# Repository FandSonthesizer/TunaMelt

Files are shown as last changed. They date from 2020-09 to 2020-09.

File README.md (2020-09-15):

# TunaMelt
Our Tuna Melt clone. 

This is out attempt to build a Tuna Melt clone. We changed it to have a true bypass, also we are using standart parts which are not hard to get by.
The Vactrol consists of an LDR03 light sensitive resistor and a white 3mm LED, bound together head on head with some black electrical tape.

So we re-named it the FnS Melt. :-)

This effect just sounds great, a very nice Tremolo indeed!

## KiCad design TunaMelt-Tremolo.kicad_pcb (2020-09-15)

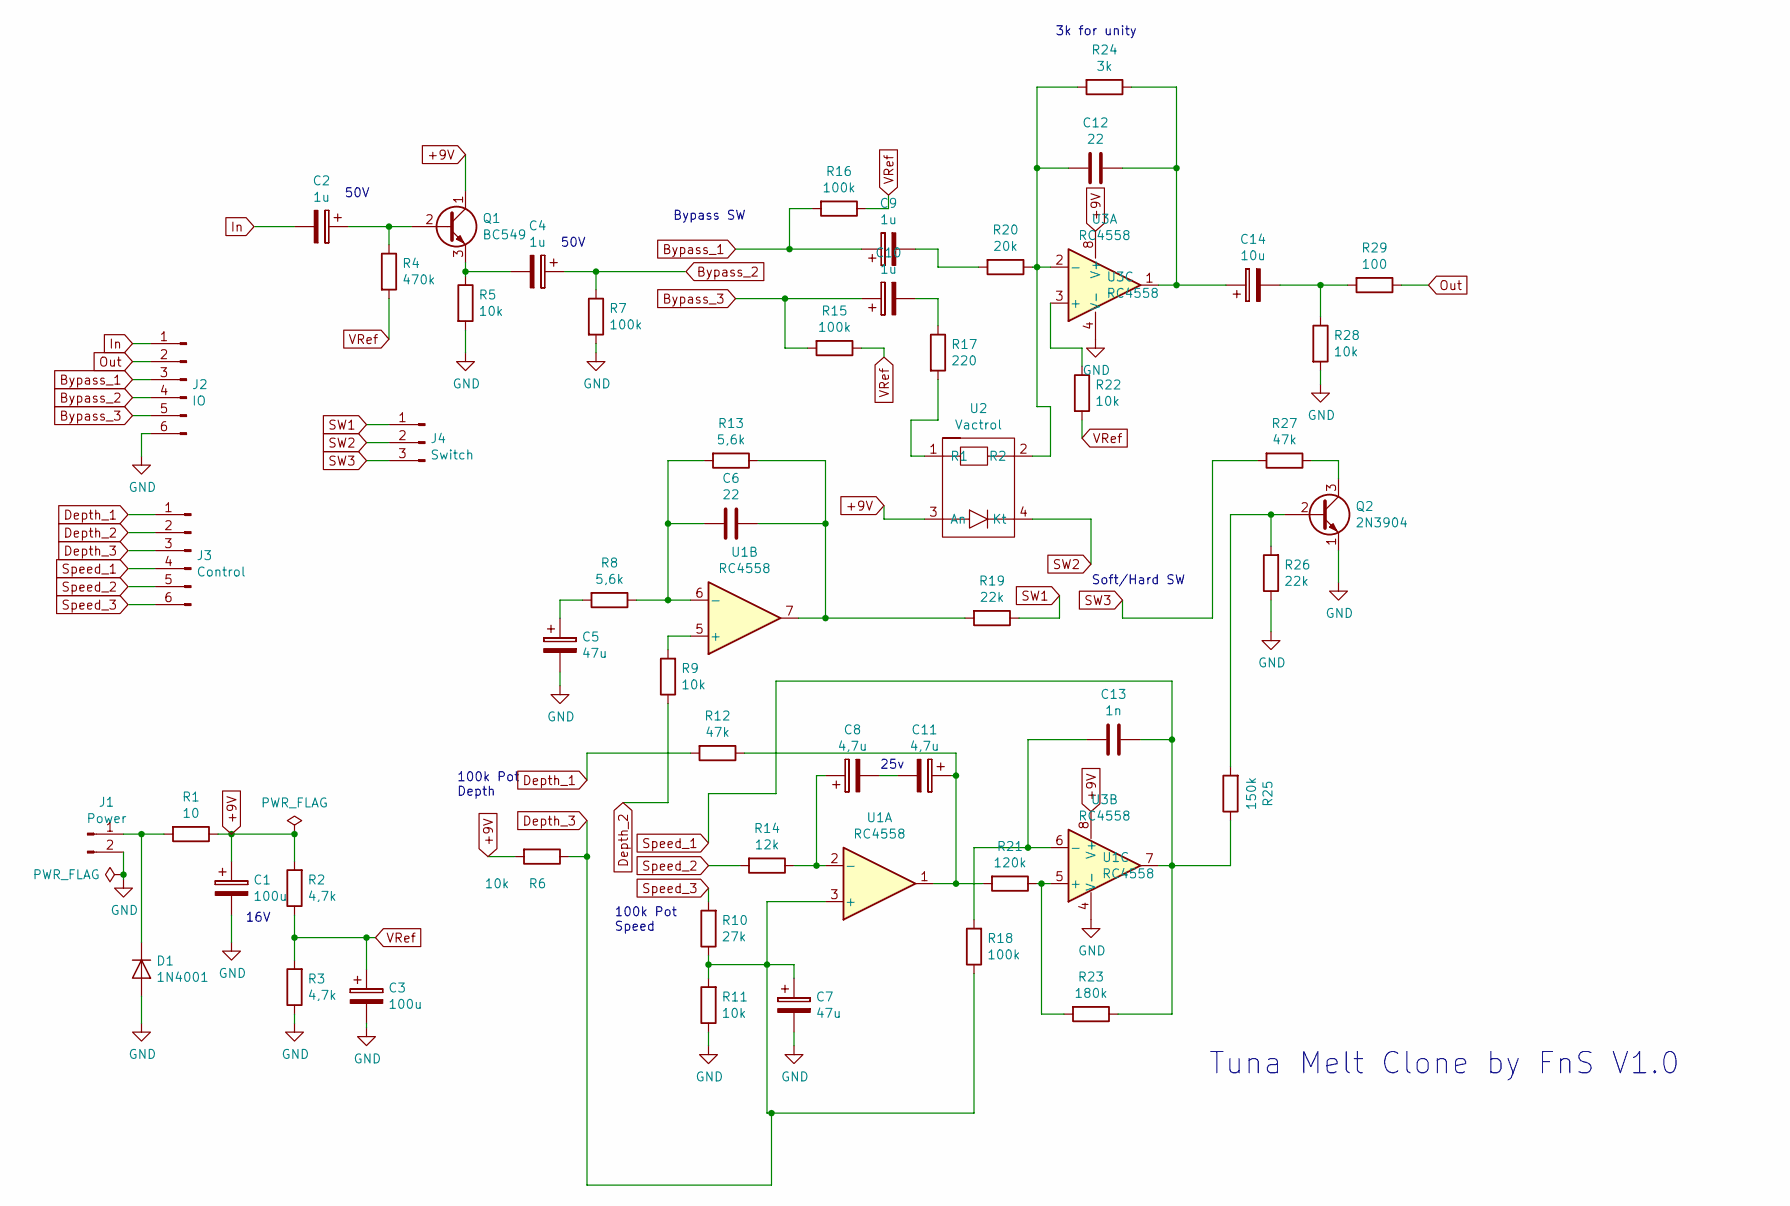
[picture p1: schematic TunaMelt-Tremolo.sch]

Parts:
C1, C3: 100u; Elko_D6.3mm_P2.50mm
C2, C4, C9, C10: 1u; Elko_D6.3mm_P2.50mm
C5, C7: 47u; Elko_D6.3mm_P2.50mm
C6, C12: 22; Kondensator_Keramik
C8, C11: 4,7u; Elko_D6.3mm_P2.50mm
C13: 1n; Kondensator_Keramik
C14: 10u; Elko_D6.3mm_P2.50mm
D1: 1N4001; Diode_Horizontal
J1: Power; Stift_x02
J2: IO; PinHeader_1x06_P2.54mm_Vertical_NIK
J3: Control; PinHeader_1x06_P2.54mm_Vertical_NIK
J4: Switch; Stift_0x3
Q1: BC549; TO-92_Wide_NIK
Q2: 2N3904; TO-92_Wide_NIK
R1: 10; Widerstand_liegend
R2, R3: 4,7k; Widerstand_liegend
R4: 470k; Widerstand_liegend
R5, R6, R9, R11, R22, R28: 10k; Widerstand_liegend
R7, R15, R16, R18: 100k; Widerstand_liegend
R8, R13: 5,6k; Widerstand_liegend
R10: 27k; Widerstand_liegend
R12, R27: 47k; Widerstand_liegend
R14: 12k; Widerstand_liegend
R17: 220; Widerstand_liegend
R19, R26: 22k; Widerstand_liegend
R20: 20k; Widerstand_liegend
R21: 120k; Widerstand_liegend
R23: 180k; Widerstand_liegend
R24: 3k; Widerstand_liegend
R25: 150k; Widerstand_liegend
R29: 100; Widerstand_liegend
U1, U3: RC4558; DIP-8_W7.62mm_Socket_LongPads
U2: Vactrol

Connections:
+9V: C1.1, Q1.1 (C), R1.1, R2.2, R6.2, U1.8 (V+), U2.3 (An), U3.8 (V+)
Bypass_1: C9.1, J2.3, R16.2
Bypass_2: C4.1, J2.4, R7.1
Bypass_3: C10.1, J2.5, R15.2
Depth_1: J3.1, R12.2
Depth_2: J3.2, R9.1
Depth_3: C7.1, J3.3, R6.1, R10.1, R11.2, R18.1, U1.3 (+)
GND: C1.2, C3.2, C5.2, C7.2, D1.2 (A), J1.2, J2.6, Q2.1 (E), R3.1, R5.2, R7.2, R11.1, R26.1, R28.2, U1.4 (V-), U3.4 (V-)
In: C2.2, J2.1
unnamed: C2.1, Q1.2 (B), R4.1
unnamed: C4.2, Q1.3 (E), R5.1
unnamed: C5.1, R8.2
unnamed: C6.1, R13.1, R19.2, U1.7
unnamed: C6.2, R8.1, R13.2, U1.6 (-)
unnamed: C8.1, R14.1, U1.2 (-)
unnamed: C9.2, R20.2
unnamed: C10.2, R17.1
unnamed: C11.1, R12.1, R21.2, U1.1
unnamed: C8.2, C11.2
unnamed: C12.1, C14.1, R24.1, U3.1
unnamed: C12.2, R20.1, R24.2, U2.2 (R2), U3.2 (-)
unnamed: C13.2, R18.2, U3.6 (-)
unnamed: C14.2, R28.1, R29.2
unnamed: D1.1 (K), J1.1, R1.2
unnamed: Q2.2 (B), R25.2, R26.2
unnamed: Q2.3 (C), R27.1
unnamed: R9.2, U1.5 (+)
unnamed: R17.2, U2.1 (R1)
unnamed: R21.1, R23.2, U3.5 (+)
unnamed: R22.1, U3.3 (+)
Out: J2.2, R29.1
SW1: J4.1, R19.1
SW2: J4.2, U2.4 (Kt)
SW3: J4.3, R27.2
Speed_1: C13.1, J3.4, R23.1, R25.1, U3.7
Speed_2: J3.5, R14.2
Speed_3: J3.6, R10.2
VRef: C3.1, R2.1, R3.2, R4.2, R15.1, R16.1, R22.2

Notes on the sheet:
50V
Bypass SW
Soft/Hard SW
100k Pot Depth
100k Pot Speed
16V
25v
Tuna Melt Clone by FnS V1.0
3k for unity

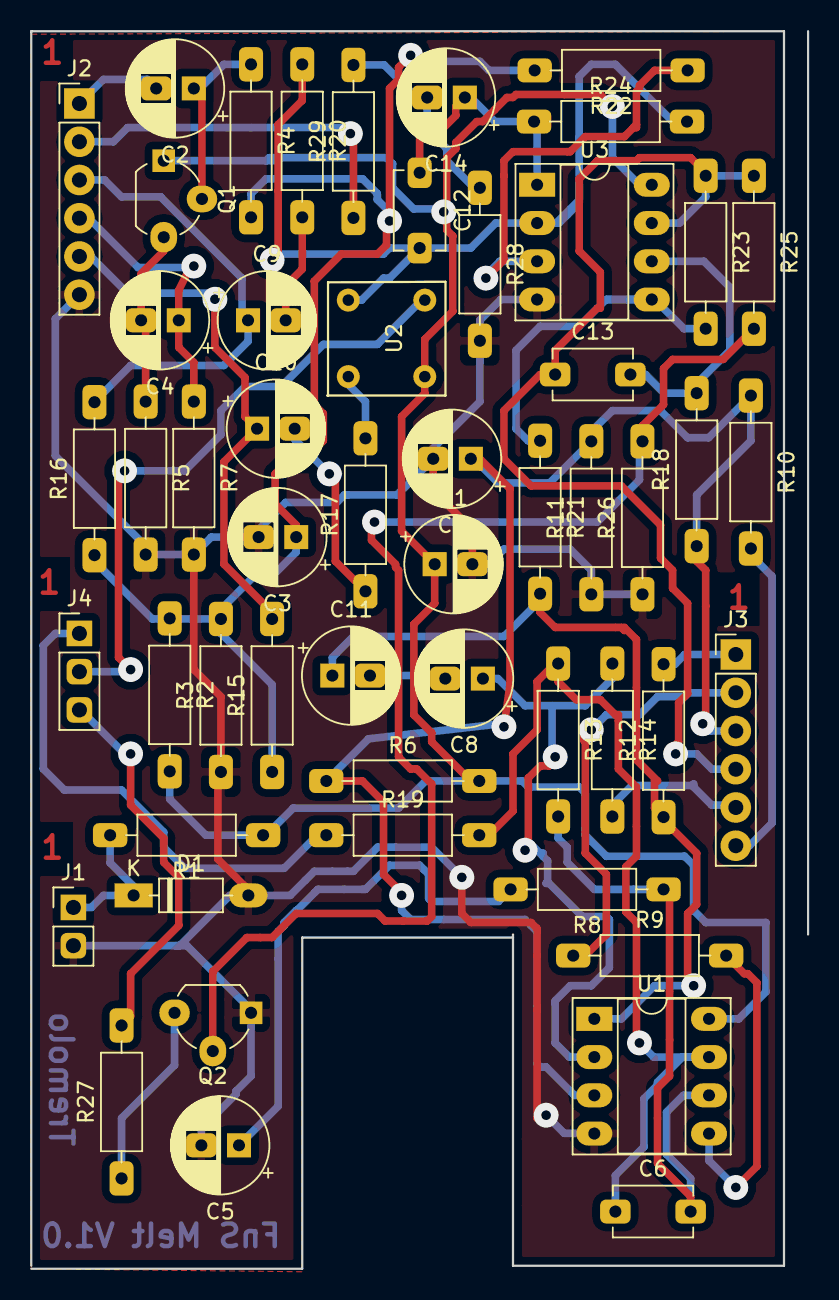
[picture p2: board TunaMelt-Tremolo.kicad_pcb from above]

Board: 2 copper layers, 51.6 x 82.2 mm, 53 parts (0 on the bottom side), 38 nets.
